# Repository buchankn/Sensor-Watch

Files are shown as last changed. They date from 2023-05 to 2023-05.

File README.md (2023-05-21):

Casio F-91W Step Counter
========================

This is a fork of Joey Castillo's Sensor-Watch (see https://github.com/joeycastillo/Sensor-Watch, and https://www.sensorwatch.net/). My changes to this fork is a work-in-progress.

My main goals are to:

* Add led 'side-lighting' to the right side of the LCD as well as the left
* Add a BMA400 accelerometer to the board for step counting, and perhaps experiment with wake-on-arm-lift, etc
* Add PAM8904E for a louder (and adjustable) piezo driver
* Remove USB, and add SWD Tag-Connect pads
* Add additional SWD pads on back of board (covered with tape when watch is assembled with the battery)

I replaced the 2 color led side light with 2 individual 0603 LEDs, so I could pick and choose each LED. Will it be better than the bi-color? We'll see... I chose not to go with an RGB LED, because I wanted LEDs on both sides of the display, and I couldn't spare 6 gpio for them. And I didn't want to connect multiple LEDs to one gpio, because it could exceed the max current for the gpio pin.

I also added a TPS610985 to the board, to ensure that the board always gets a stable 3V supply, and the voltage supply to the LEDs doesn't dip below the LED forward voltage. The GPIO pins have a higher rated current at 3V, so this also ensures that turning on the LEDs doesn't exceed the max GPIO current. Using a boost converter will decrease battery life, but it's still to be determined by how much. The TPS610985 is pretty amazingly efficient, so I'm hoping to still get decent battery life with it.

The PAM8904E should make the buzzer on the watch louder, and the voltage to the buzzer is adjustable by 3 levels, so there's a sort of volume control with it.

I added Tag-Connect pads to make programming the board easier, without having to mess with custom POGO pins and such. Also, the SWD pads on the back of the board will allow me to assemble the board with the LCD, but without the battery, and solder wires to the debug pads to debug the board with the LCD connected. This of course means there is no bootloader, and the board can only be programmed using SWD.

Kicad design files to be uploaded shortly, and I'll update the code in this repository to match all the changes/additions I made...

Prototype boards have been ordered from PCBWay! Crossing my fingers that I didn't miss anything :)

Things I plan on fixing/improving on version 2.0 of the PCB:

* I accidently placed a resistor in a "keep out" zone, where the white case touches the PCB. I'll have to cut the case a little for these boards to fit.
* Connect ENABLE_SECONDARY_POWER to a gpio pin, so that the transient response of the boost regulator can be improved during active mode (I'm thinking about the times I'm using PWM for the LEDs and buzzer).
* See if I can connect all three buttons to an RTC wake pin.

Here's a picture of the new pin assignemts I plan for version 2.0 of the PCB:

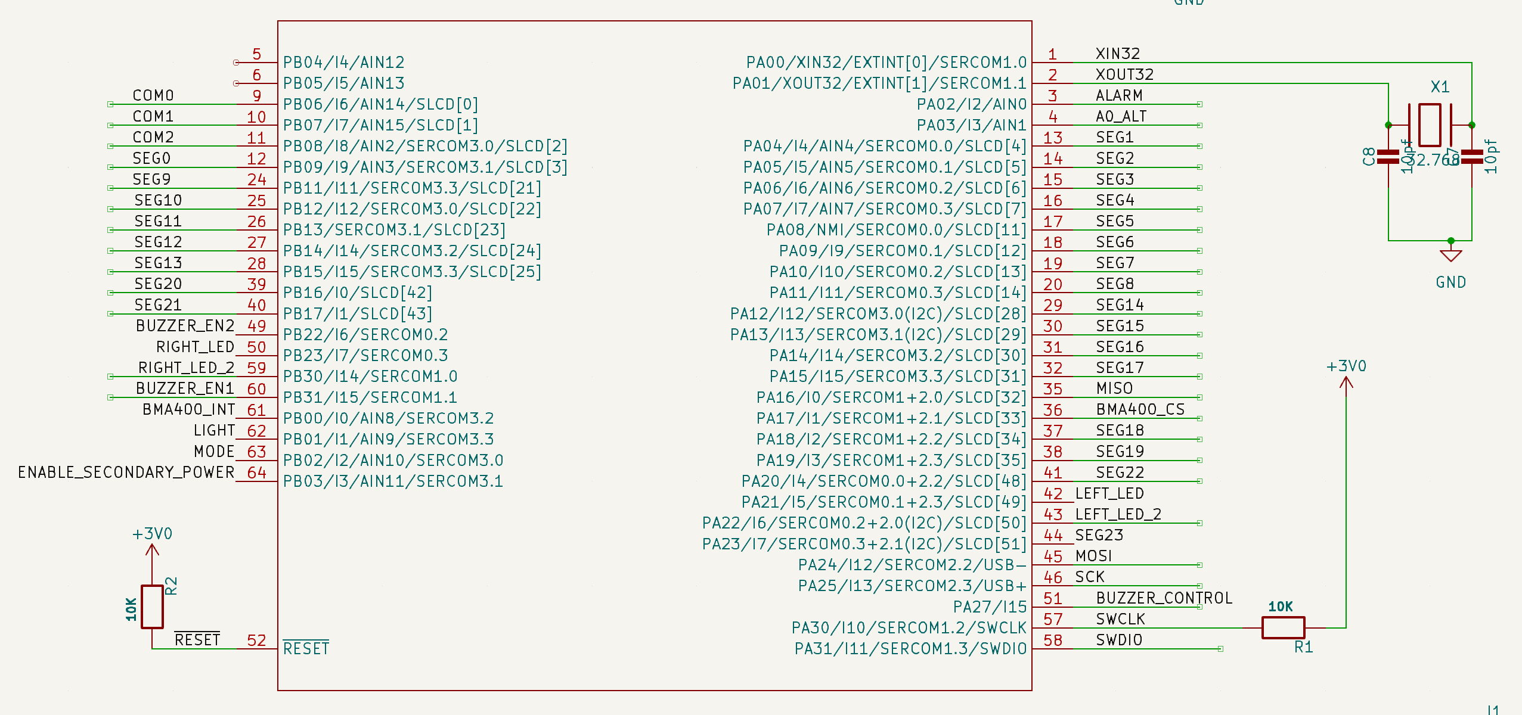
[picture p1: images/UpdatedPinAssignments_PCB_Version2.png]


And pictures of version 1.0 of the PCB:

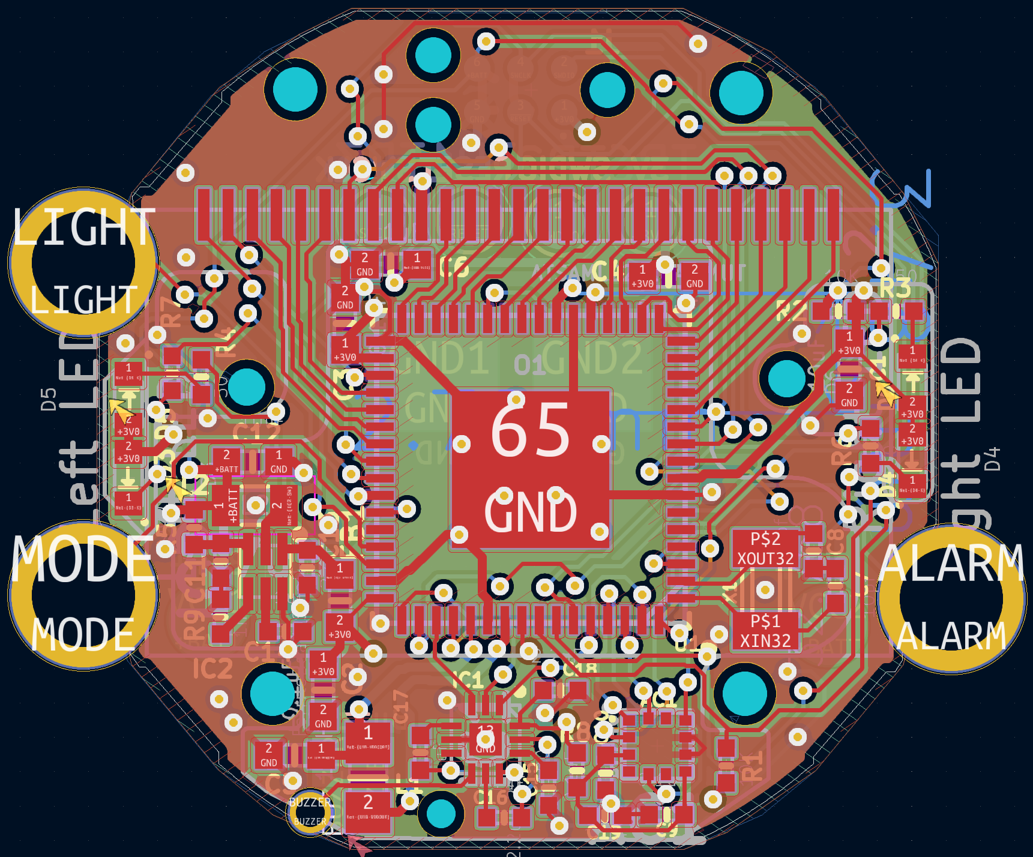
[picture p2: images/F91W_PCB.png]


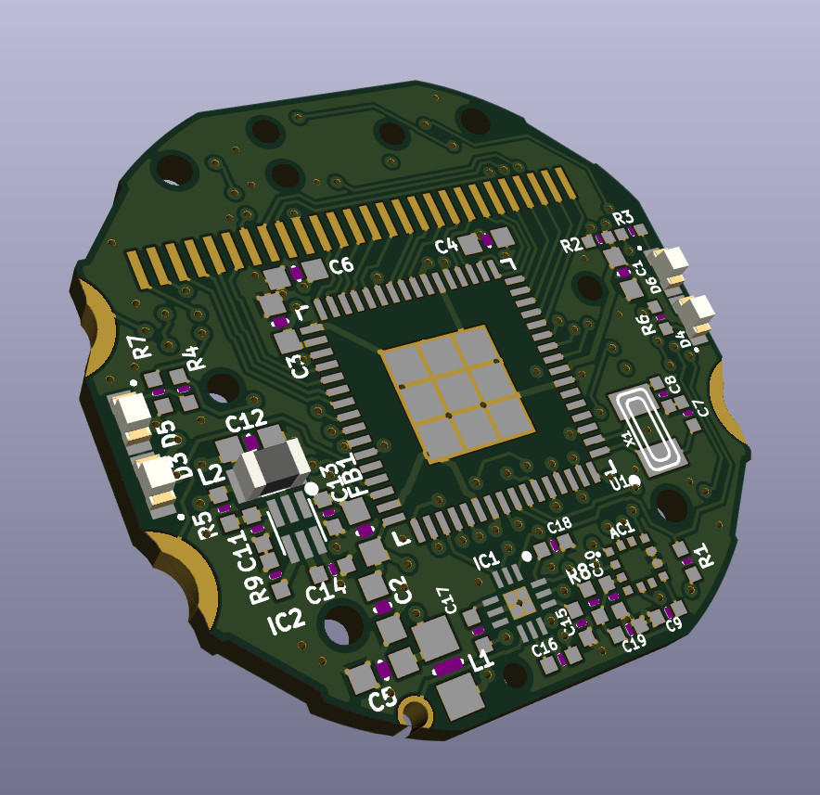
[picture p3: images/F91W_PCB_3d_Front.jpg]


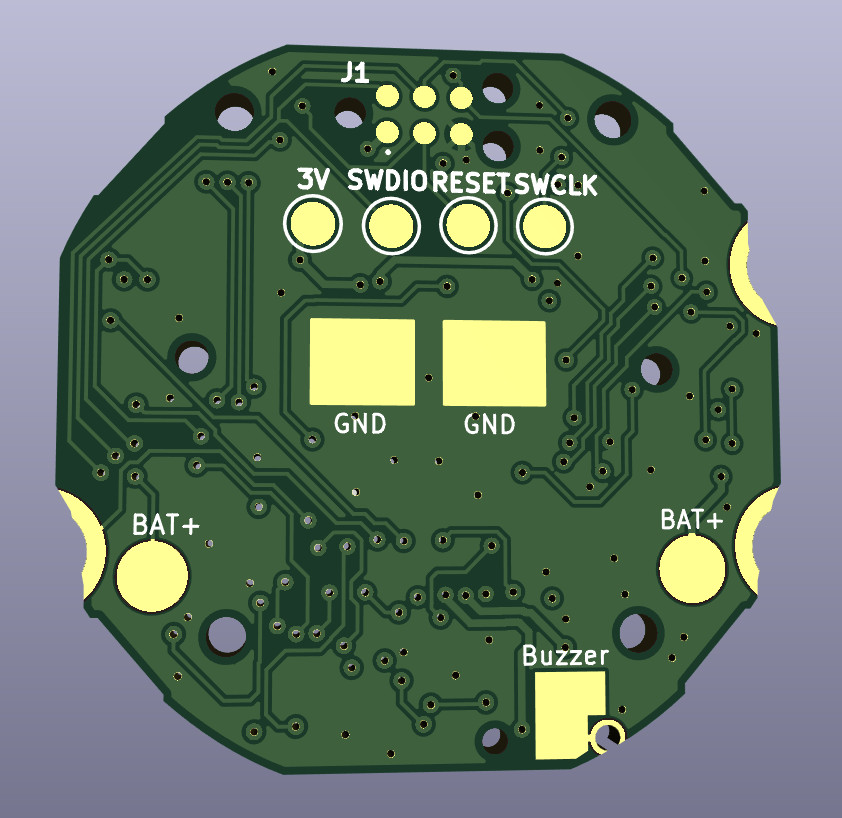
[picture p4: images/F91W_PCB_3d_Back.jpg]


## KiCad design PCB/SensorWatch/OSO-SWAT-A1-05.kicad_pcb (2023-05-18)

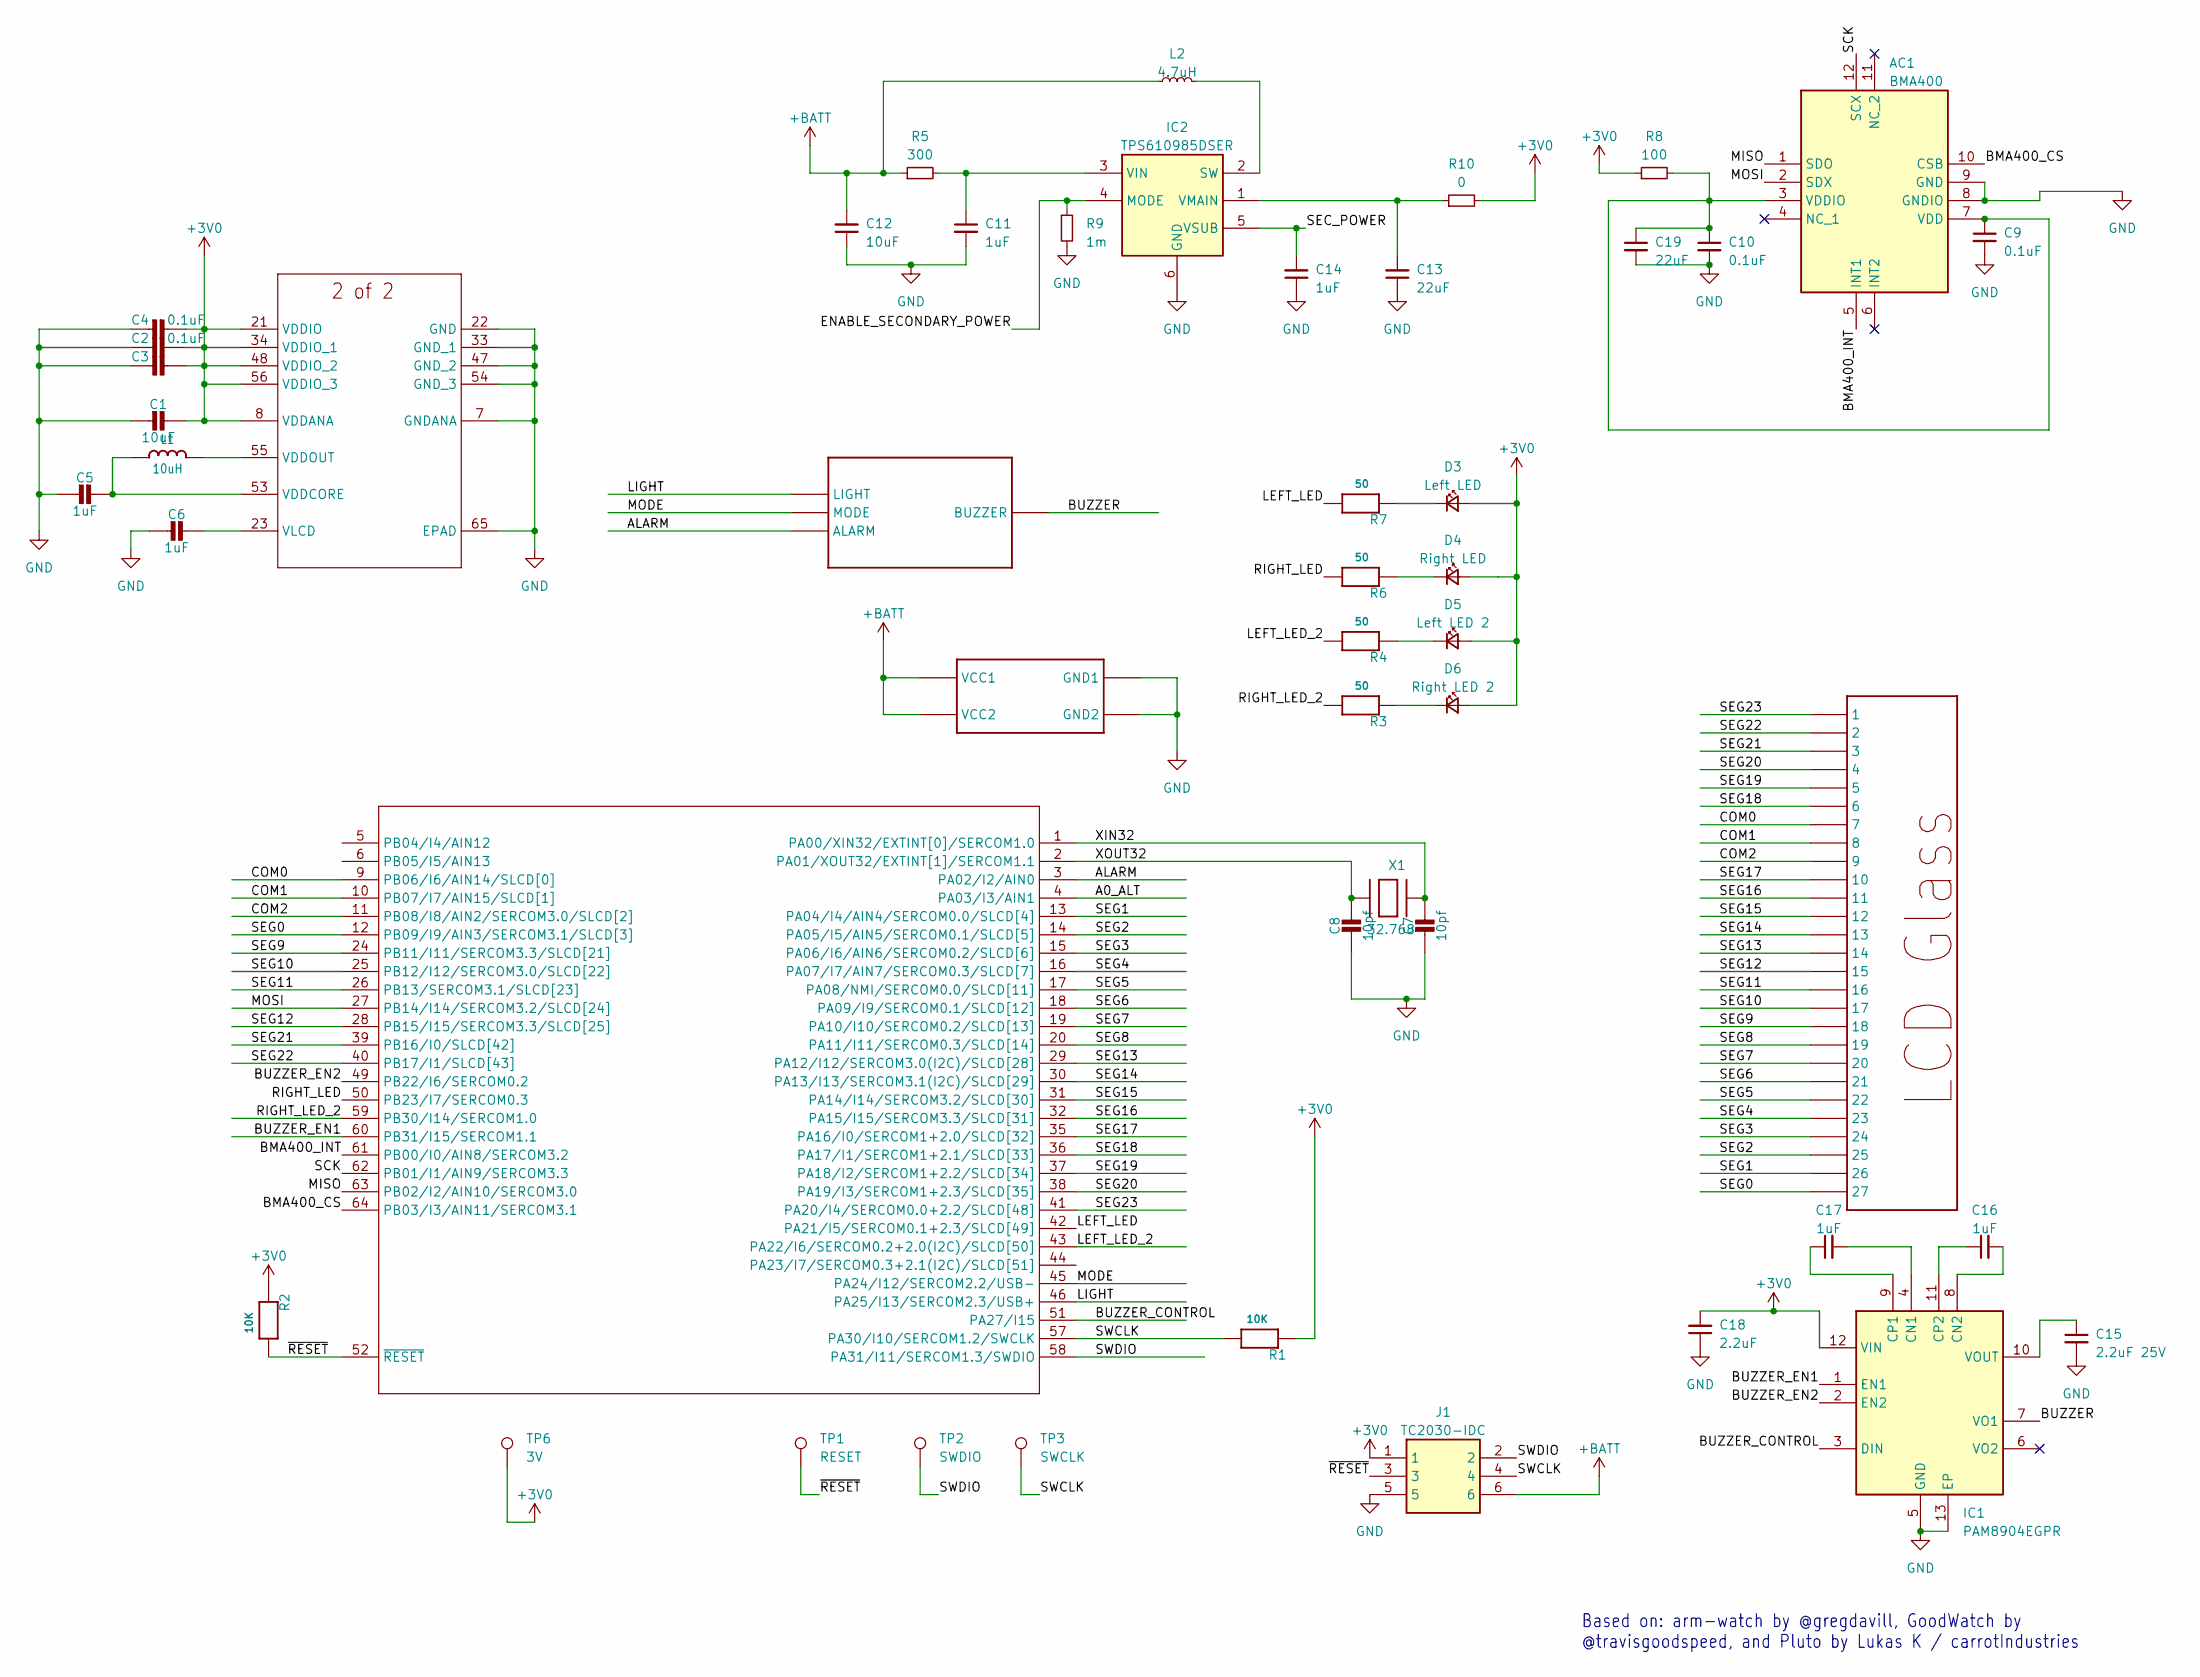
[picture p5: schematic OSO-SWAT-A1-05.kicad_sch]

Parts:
AC1: BMA400; BOSCH_LGA-12; Mouser2 Part Number 262-BMA400
C1, C12: 10uF; _0603MP
C2, C3, C4: 0.1uF; _0603MP
C5, C6: 1uF; _0603MP
C7, C8: 10pf; _0402MP
C9, C10: 0.1uF; _0402MP
C11, C14, C16, C17: 1uF; _0402MP
C13, C19: 22uF; _0402MP
C15: 2.2uF 25V; _0402MP
C18: 2.2uF; _0402MP
D3: Left LED; LED_APHD1608LZGCK; Part APHD1608LZGCK (GREEN)
D4: Right LED; LED_APHD1608LZGCK; Part APHD1608LZGCK (GREEN)
D5: Left LED 2; LED_APHD1608LZGCK; Part APHD1608LVBC/D (BLUE)
D6: Right LED 2; LED_APHD1608LZGCK; Part APHD1608LVBC/D (BLUE)
IC1: PAM8904EGPR; Mouser2 Part Number 621-PAM8904EGPR
IC2: TPS610985DSER; Manufacturer_Part_Number TPS610985DSER
J1: TC2030-IDC; TC2030IDC; Manufacturer_Part_Number TC2030-IDC
L1: 10uH; MICROBUILDER__0805MP
L2: 4.7uH; L_0805_2012Metric; Part Wurth 74438323047
O1: CASIO-F91W-OUTLINE-TAG-CONNECT
R1, R2: 10K; _0402MP
R3, R4, R6, R7: 50; _0402MP
R5: 300; _0402MP; Part Vishay Dale CRCW0402300RJNED
R8: 100; _0402MP; Part Vishay Dale CRCW0402300RJNED
R9: 1m; _0402MP
R10: 0; _0603MP; Part Vishay Dale CRCW0402300RJNED
TP1: RESET; TestPoint_Pad_D1.5mm
TP2: SWDIO; TestPoint_Pad_D1.5mm
TP3: SWCLK; TestPoint_Pad_D1.5mm
TP6: 3V; TestPoint_Pad_D1.5mm
U1: ATSAML22J18A-MUT; QFN64_9X9MC_MCH
X1: 32.768; XTAL3215

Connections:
+3V0: C1.1, C2.1, C3.1, C4.1, C18.2, D3.2 (A), D4.2 (A), D5.2 (A), D6.2 (A), IC1.12 (VIN), J1.1, R1.1, R2.1, R8.1, R10.2, TP6.1, U1.8 (VDDANA), U1.21 (VDDIO), U1.34 (VDDIO_1), U1.48 (VDDIO_2), U1.56 (VDDIO_3); also elsewhere on the board
+BATT: C12.2, J1.6, L2.1, O1.VCC1, O1.VCC2, R5.1
/A0_ALT: U1.4 (PA03/I3/AIN1)
/ALARM: O1.ALARM, U1.3 (PA02/I2/AIN0)
/BMA400_CS: AC1.10 (CSB), U1.64 (PB03/I3/AIN11/SERCOM3.1)
/BMA400_INT: AC1.5 (INT1), U1.61 (PB00/I0/AIN8/SERCOM3.2)
/BUZZER: IC1.7 (VO1), O1.BUZZER
/BUZZER_CONTROL: IC1.3 (DIN), U1.51 (PA27/I15)
/BUZZER_EN1: IC1.1 (EN1), U1.60 (PB31/I15/SERCOM1.1)
/BUZZER_EN2: IC1.2 (EN2), U1.49 (PB22/I6/SERCOM0.2)
/COM0: O1.7, U1.9 (PB06/I6/AIN14/SLCD[0])
/COM1: O1.8, U1.10 (PB07/I7/AIN15/SLCD[1])
/COM2: O1.9, U1.11 (PB08/I8/AIN2/SERCOM3.0/SLCD[2])
/ENABLE_SECONDARY_POWER: IC2.4 (MODE), R9.1
/LEFT_LED: R7.2, U1.42 (PA21/I5/SERCOM0.1+2.3/SLCD[49])
/LEFT_LED_2: R4.2, U1.43 (PA22/I6/SERCOM0.2+2.0(I2C)/SLCD[50])
/LIGHT: O1.LIGHT, U1.46 (PA25/I13/SERCOM2.3/USB+)
/MISO: AC1.1 (SDO), U1.63 (PB02/I2/AIN10/SERCOM3.0)
/MODE: O1.MODE, U1.45 (PA24/I12/SERCOM2.2/USB-)
/MOSI: AC1.2 (SDX), U1.27 (PB14/I14/SERCOM3.2/SLCD[24])
/RIGHT_LED: R6.2, U1.50 (PB23/I7/SERCOM0.3)
/RIGHT_LED_2: R3.2, U1.59 (PB30/I14/SERCOM1.0)
/SCK: AC1.12 (SCX), U1.62 (PB01/I1/AIN9/SERCOM3.3)
/SEC_POWER: C14.2, IC2.5 (VSUB)
/SEG0: O1.27, U1.12 (PB09/I9/AIN3/SERCOM3.1/SLCD[3])
/SEG1: O1.26, U1.13 (PA04/I4/AIN4/SERCOM0.0/SLCD[4])
/SEG2: O1.25, U1.14 (PA05/I5/AIN5/SERCOM0.1/SLCD[5])
/SEG3: O1.24, U1.15 (PA06/I6/AIN6/SERCOM0.2/SLCD[6])
/SEG4: O1.23, U1.16 (PA07/I7/AIN7/SERCOM0.3/SLCD[7])
/SEG5: O1.22, U1.17 (PA08/NMI/SERCOM0.0/SLCD[11])
/SEG6: O1.21, U1.18 (PA09/I9/SERCOM0.1/SLCD[12])
/SEG7: O1.20, U1.19 (PA10/I10/SERCOM0.2/SLCD[13])
/SEG8: O1.19, U1.20 (PA11/I11/SERCOM0.3/SLCD[14])
/SEG9: O1.18, U1.24 (PB11/I11/SERCOM3.3/SLCD[21])
/SEG10: O1.17, U1.25 (PB12/I12/SERCOM3.0/SLCD[22])
/SEG11: O1.16, U1.26 (PB13/SERCOM3.1/SLCD[23])
/SEG12: O1.15, U1.28 (PB15/I15/SERCOM3.3/SLCD[25])
/SEG13: O1.14, U1.29 (PA12/I12/SERCOM3.0(I2C)/SLCD[28])
/SEG14: O1.13, U1.30 (PA13/I13/SERCOM3.1(I2C)/SLCD[29])
/SEG15: O1.12, U1.31 (PA14/I14/SERCOM3.2/SLCD[30])
/SEG16: O1.11, U1.32 (PA15/I15/SERCOM3.3/SLCD[31])
/SEG17: O1.10, U1.35 (PA16/I0/SERCOM1+2.0/SLCD[32])
/SEG18: O1.6, U1.36 (PA17/I1/SERCOM1+2.1/SLCD[33])
/SEG19: O1.5, U1.37 (PA18/I2/SERCOM1+2.2/SLCD[34])
/SEG20: O1.4, U1.38 (PA19/I3/SERCOM1+2.3/SLCD[35])
/SEG21: O1.3, U1.39 (PB16/I0/SLCD[42])
/SEG22: O1.2, U1.40 (PB17/I1/SLCD[43])
/SEG23: O1.1, U1.41 (PA20/I4/SERCOM0.0+2.2/SLCD[48])
/SWCLK: J1.4, R1.2, TP3.1, U1.57 (PA30/I10/SERCOM1.2/SWCLK)
/SWDIO: J1.2, TP2.1, U1.58 (PA31/I11/SERCOM1.3/SWDIO)
/XIN32: C7.1, U1.1 (PA00/XIN32/EXTINT[0]/SERCOM1.0), X1.P$1
/XOUT32: C8.1, U1.2 (PA01/XOUT32/EXTINT[1]/SERCOM1.1), X1.P$2
/~RESET: J1.3, R2.2, TP1.1, U1.52 (~RESET)
GND: AC1.8 (GNDIO), AC1.9 (GND), C1.2, C2.2, C3.2, C4.2, C5.2, C6.2, C7.2, C8.2, C9.2, C10.2, C11.2, C12.1, C13.1, C14.1, C15.2, C18.1, C19.2, IC1.5 (GND), IC1.13 (EP), IC2.6 (GND), J1.5, O1.GND1, O1.GND2, R9.2, U1.7 (GNDANA), U1.22 (GND), U1.33 (GND_1), U1.47 (GND_2), U1.54 (GND_3), U1.65 (EPAD)
unnamed: AC1.3 (VDDIO), AC1.7 (VDD), C9.1, C10.1, C19.1, R8.2
unnamed: D3.1 (K), R7.1
unnamed: D4.1 (K), R6.1
unnamed: D5.1 (K), R4.1
unnamed: D6.1 (K), R3.1
unnamed: C17.2, IC1.4 (CN1)
unnamed: C16.2, IC1.8 (CN2)
unnamed: C17.1, IC1.9 (CP1)
unnamed: C16.1, IC1.11 (CP2)
unnamed: C15.1, IC1.10 (VOUT)
unnamed: IC2.2 (SW), L2.2
unnamed: C11.1, IC2.3 (VIN), R5.2
unnamed 66: C13.2, IC2.1 (VMAIN), R10.1; also elsewhere on the board
unnamed: C5.1, L1.1, U1.53 (VDDCORE)
unnamed: L1.2, U1.55 (VDDOUT)
unnamed: C6.1, U1.23 (VLCD)

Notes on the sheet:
Based on: arm-watch by @gregdavill, GoodWatch by @travisgoodspeed, and Pluto by Lukas K / carrotIndustries

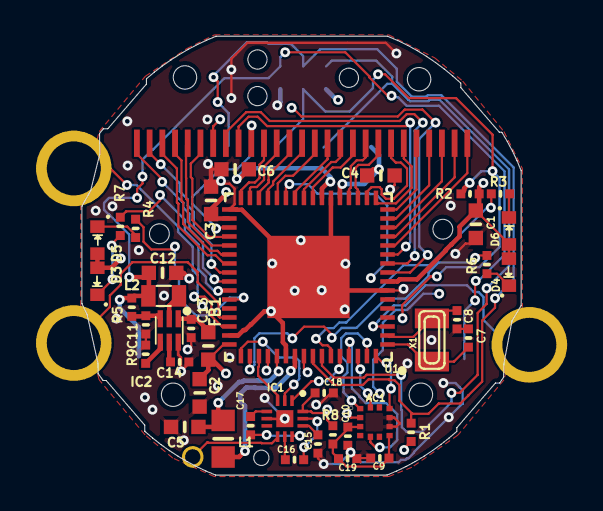
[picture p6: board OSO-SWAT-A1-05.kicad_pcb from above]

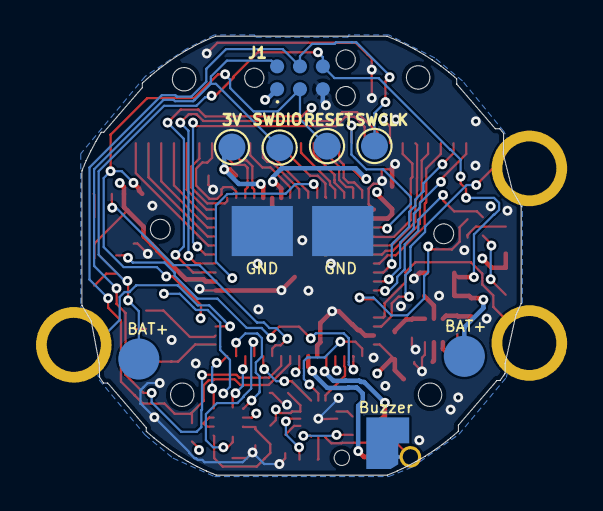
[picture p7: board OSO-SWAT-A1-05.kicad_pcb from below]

Board: 4 copper layers, 24.4 x 24.4 mm, 46 parts (5 on the bottom side), 69 nets.

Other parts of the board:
FB1: FerriteBead_Small; _0603MP

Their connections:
+3V0: FB1.2; also elsewhere on the board
unnamed 66: FB1.1; also elsewhere on the board

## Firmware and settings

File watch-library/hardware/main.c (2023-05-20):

/*
 * MIT License
 *
 * Copyright (c) 2021 Joey Castillo
 *
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
 * THE SOFTWARE IS PROVIDED "AS IS", WITHOUT WARRANTY OF ANY KIND, EXPRESS OR
 * IMPLIED, INCLUDING BUT NOT LIMITED TO THE WARRANTIES OF MERCHANTABILITY,
 * FITNESS FOR A PARTICULAR PURPOSE AND NONINFRINGEMENT. IN NO EVENT SHALL THE
 * AUTHORS OR COPYRIGHT HOLDERS BE LIABLE FOR ANY CLAIM, DAMAGES OR OTHER
 * LIABILITY, WHETHER IN AN ACTION OF CONTRACT, TORT OR OTHERWISE, ARISING FROM,
 * OUT OF OR IN CONNECTION WITH THE SOFTWARE OR THE USE OR OTHER DEALINGS IN THE
 * SOFTWARE.
 */

//-----------------------------------------------------------------------------
#include <stdlib.h>
#include <stdint.h>
#include <stdbool.h>
#include <string.h>
#include <stdio.h>
#include "saml22.h"
#include "hal_init.h"
#include "watch.h"
#include "tusb.h"

int main(void) {
    // ASF code. Initialize the MCU with configuration options from Atmel Studio.
    init_mcu();

#if BOARD != F91W-PEDOMETER
#warning Enabline USB on this board
    // check if we are plugged into USB power.
    watch_enable_digital_input(VBUS_DET);
    watch_enable_pull_down(VBUS_DET);
    if (watch_get_pin_level(VBUS_DET)) {
        // if so, enable USB functionality.
        _watch_enable_usb();
    }
    watch_disable_digital_input(VBUS_DET);
#else
#warning No USB on this board
#endif

    // initialize the delay driver before any user code is called.
    delay_driver_init();

    // User code. Give the app a chance to initialize its data structures and state.
    app_init();

    // If the RTC is already enabled, we're either waking from BACKUP mode or a reset.
    // Ideally we should check if the TAMPER or CMP0 (alarm) flags are set.
    if (_watch_rtc_is_enabled()) {
        // User code. Give the application a chance to restore state from backup registers.
        app_wake_from_backup();

        // disable the tamper interrupt and clear the tamper bit
        hri_rtcmode0_clear_INTEN_TAMPER_bit(RTC);
        hri_rtcmode0_clear_interrupt_TAMPER_bit(RTC);
    }

    // Watch library code. Set initial parameters for the device and enable the RTC.
    _watch_init();

    // if date/time register is 0 (power on reset state), default year to 2022.
    watch_date_time date_time = watch_rtc_get_date_time();
    if (date_time.reg == 0) {
        date_time.unit.year = 2;
        watch_rtc_set_date_time(date_time);
    }

    // User code. Give the app a chance to enable and set up peripherals.
    app_setup();

    while (1) {
        bool usb_enabled = hri_usbdevice_get_CTRLA_ENABLE_bit(USB);
        bool can_sleep = app_loop();

        if (can_sleep && !usb_enabled) {
            app_prepare_for_standby();
            sleep(4);
            app_wake_from_standby();
        }
    }

    return 0;
}

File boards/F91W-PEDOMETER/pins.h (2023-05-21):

#ifndef PINS_H_INCLUDED
#define PINS_H_INCLUDED

// Buttons
#define BTN_ALARM GPIO(GPIO_PORTA, 2)
#define WATCH_BTN_ALARM_EIC_CHANNEL 2
#define BTN_LIGHT GPIO(GPIO_PORTA, 25)
#define WATCH_BTN_LIGHT_EIC_CHANNEL 13
#define BTN_MODE GPIO(GPIO_PORTA, 24)
#define WATCH_BTN_MODE_EIC_CHANNEL 12

// Buzzer
#define BUZZER GPIO(GPIO_PORTA, 27)
#define WATCH_BUZZER_TCC_PINMUX PINMUX_PA27F_TCC0_WO5
#define WATCH_BUZZER_TCC_CHANNEL 1

#define BUZZER_EN_1 GPIO(GPIO_PORTB, 31)
#define BUZZER_EN_2 GPIO(GPIO_PORTB, 22)

// LEDs
#define WATCH_INVERT_LED_POLARITY
#define WATCH_LED_1_TCC_CHANNEL 3
#define WATCH_LED_2_TCC_CHANNEL 0

#define LEFT_LED_1 GPIO(GPIO_PORTA, 21)
#define WATCH_LEFT_LED_1_TCC_PINMUX PINMUX_PA21F_TCC0_WO7

#define LEFT_LED_2 GPIO(GPIO_PORTA, 22)
#define WATCH_LEFT_LED_2_TCC_PINMUX PINMUX_PA22F_TCC0_WO4

#define RIGHT_LED_1 GPIO(GPIO_PORTB, 23)
#define WATCH_RIGHT_LED_1_TCC_PINMUX PINMUX_PB23F_TCC0_WO3

#define RIGHT_LED_2 GPIO(GPIO_PORTB, 30)
#define WATCH_RIGHT_LED_2_TCC_PINMUX PINMUX_PB30E_TCC0_WO0


// Segment LCD
#define SLCD0 GPIO(GPIO_PORTB, 6)   // COM0
#define SLCD1 GPIO(GPIO_PORTB, 7)   // COM1
#define SLCD2 GPIO(GPIO_PORTB, 8)   // COM2
#define SLCD3 GPIO(GPIO_PORTB, 9)   // SEG0
#define SLCD4 GPIO(GPIO_PORTA, 4)   // SEG1
#define SLCD5 GPIO(GPIO_PORTA, 5)   // SEG2
#define SLCD6 GPIO(GPIO_PORTA, 6)   // SEG3
#define SLCD7 GPIO(GPIO_PORTA, 7)   // SEG4
#define SLCD8 GPIO(GPIO_PORTA, 8)  // SEG5
#define SLCD9 GPIO(GPIO_PORTA, 9)  // SEG6
#define SLCD10 GPIO(GPIO_PORTA, 10) // SEG7
#define SLCD11 GPIO(GPIO_PORTA, 11) // SEG8
#define SLCD12 GPIO(GPIO_PORTB, 11) // SEG9
#define SLCD13 GPIO(GPIO_PORTB, 12) // SEG10
#define SLCD14 GPIO(GPIO_PORTB, 13) // SEG11
#define SLCD15 GPIO(GPIO_PORTB, 15) // SEG12
#define SLCD16 GPIO(GPIO_PORTA, 12) // SEG13
#define SLCD17 GPIO(GPIO_PORTA, 13) // SEG14
#define SLCD18 GPIO(GPIO_PORTA, 14) // SEG15
#define SLCD19 GPIO(GPIO_PORTA, 15) // SEG16
#define SLCD20 GPIO(GPIO_PORTA, 16) // SEG17
#define SLCD21 GPIO(GPIO_PORTA, 17) // SEG18
#define SLCD22 GPIO(GPIO_PORTA, 18) // SEG19
#define SLCD23 GPIO(GPIO_PORTA, 19) // SEG20
#define SLCD24 GPIO(GPIO_PORTB, 16) // SEG21
#define SLCD25 GPIO(GPIO_PORTB, 17) // SEG22
#define SLCD26 GPIO(GPIO_PORTA, 20) // SEG23

// This board uses a slightly different pin mapping from the standard watch, and it's not enough to
// just declare the pins. We also have to set the LCD Pin Enable register with the SLCD pins we're
// using. These numbers are not port/pin numbers, but the "SLCD/LP[x]" numbers in the pinmux table.
// If not defined in pins.h, the LCD driver will fall back to the pin mapping in hpl_slcd_config.h.
// LPENL is for pins SLCD/LP[0..31].
#define CONF_SLCD_LPENL (\
        (uint32_t)1 <<  0 | \
        (uint32_t)1 <<  1 | \
        (uint32_t)1 <<  2 | \
        (uint32_t)1 <<  3 | \
        (uint32_t)1 <<  4 | \
        (uint32_t)1 <<  5 | \
        (uint32_t)1 <<  6 | \
        (uint32_t)1 <<  7 | \
        (uint32_t)1 << 11 | \
        (uint32_t)1 << 12 | \
        (uint32_t)1 << 13 | \
        (uint32_t)1 << 14 | \
        (uint32_t)1 << 21 | \
        (uint32_t)1 << 22 | \
        (uint32_t)1 << 23 | \
        (uint32_t)1 << 25 | \
        (uint32_t)1 << 28 | \
        (uint32_t)1 << 29 | \
        (uint32_t)1 << 30 | \
        (uint32_t)1 << 31 | 0)
// LPENH is for pins SLCD/LP[32..51], where bit 0 represents pin 32.
#define CONF_SLCD_LPENH (\
        (uint32_t)1 << (32 - 32) | \
        (uint32_t)1 << (33 - 32) | \
        (uint32_t)1 << (34 - 32) | \
        (uint32_t)1 << (35 - 32) | \
        (uint32_t)1 << (42 - 32) | \
        (uint32_t)1 << (43 - 32) | \
        (uint32_t)1 << (48 - 32) | 0)


// 9-pin connector
#define A0 GPIO(GPIO_PORTB, 4)
#define WATCH_A0_EIC_CHANNEL 4
#define A1 GPIO(GPIO_PORTB, 1)
#define WATCH_A1_EIC_CHANNEL 1
#define A2 GPIO(GPIO_PORTB, 2)
#define WATCH_A2_EIC_CHANNEL 2
#define A3 GPIO(GPIO_PORTB, 3)
#define WATCH_A3_EIC_CHANNEL 3
#define A4 GPIO(GPIO_PORTB, 0)
#define WATCH_A4_EIC_CHANNEL 0
#define SDA GPIO(GPIO_PORTB, 30)
#define SCL GPIO(GPIO_PORTB, 31)

// aliases for as A3/A4; these were mentioned as D0/D1 in early documentation.
#define D0 GPIO(GPIO_PORTB, 3)
#define D1 GPIO(GPIO_PORTB, 0)

#endif // PINS_H_INCLUDED

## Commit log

2023-05-18 Describe some of my sensor watch changes
2023-05-18 Add PCB pictures
2023-05-18 Add kicad project
    [BMI270-SensorBoard.brd, BMI270-SensorBoard.sch, OSO-FEAL-A1-00.brd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]
2023-05-20 Add new pins.h for F91W-PEDOMETER, and start making changes for extra LEDs (in-work)
2023-05-20 More LED fixes
2023-05-21 Add picture of new pin assignments for PCB version 2.0
